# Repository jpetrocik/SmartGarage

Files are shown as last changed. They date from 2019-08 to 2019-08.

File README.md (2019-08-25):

# SmartGarage

SmartGarage is a WIFI enabled device that works with most garage door openers. Along with opening and closing the garage door, it provides the current status of the door, whether its open or closed.  The stock firmware provides both a HTTP Restful api and MQTT based interface. No 3rd party servers are required for SmartGarage to work, you can directly operate it via a HTTP RestAPI or MQTT.  It easly intergrates with HomeAssistant, https://www.home-assistant.io/ and other home automation software.

## Controlling The Garage Door ##

RESTful Api

```
GET  http://garage.local/
Returns the current status of the door, e.g. open or closed

GET  http://garage.local/door
Operates the door, either closing it or opening it depending on what the current status is.

GET http://garage.local/config
Returns the current configuration

PUT http://garage.local/config?poperty_name=property_value
Sets the configuration property to the provided value

GET http://garage.local/restart
Reboot the device

POST http://garage.local/factoryreset
Resets the device to factory settings
```

MQTT

MQTT is a common messaging protocol used for IoT devices.  Most home automation systems like OpenHab and home-assistant.io  support mqtt messaging. If you are unfamiliar with MQTT, check out https://mosquitto.org/ to learn more.

The device listens on the command topic and publishes the status of the door on the status topic.  The command topic is used to send commands to the device to operate the garage door. The default hostname for the device is __garage__, below replace [hostname] with the hostname of the device.  If you have not changed it, it will be __garage__. 

```
garage/[hostname]/command
```

The messages published to the command topic are very simple,  just numeric numbers.  You can request the door to close, open, or toggle depending on its current state.
```
0 Close the door 
1 Open the door 
2 Toggle the door, open or close depending on current state
3 Request current status
```

If you are using mosquito the command line to open the garage door would look like this:

```
mosquito_pub -t garage/garage/command -m 1
```

When the door opens or closes, the status is published on the status topic.  The message is a json message indicating the current status.  Again, if using mosquito the command line to listen for the status change would be

```
mosquito_sub -t garage/garage/status 
```

Here is an example of the message published with the door is closed.

```
{
  "status": "CLOSED"
}
```

## Installation Guide ##

https://docs.google.com/document/d/12LUHNYjrVlYSZdDVwD1QsqcnY-EzrYETPhFzhXXMPhE/edit?usp=sharing

## Device ##

The physical PCB is about 20mm x 40mm and is powered by a mini usb cable.  Installation is straight forward and does not interfere the current operation of the garage door, all remotes and openers still work.

There are a couple options to get your hands on your own board.  You can order it directly from me on ebay.com with the latest firmware already flashed and ready to install, or you can download the Eagle files from https://github.com/jpetrocik/SmartGarage and build your own.

Image Of Device v1.1

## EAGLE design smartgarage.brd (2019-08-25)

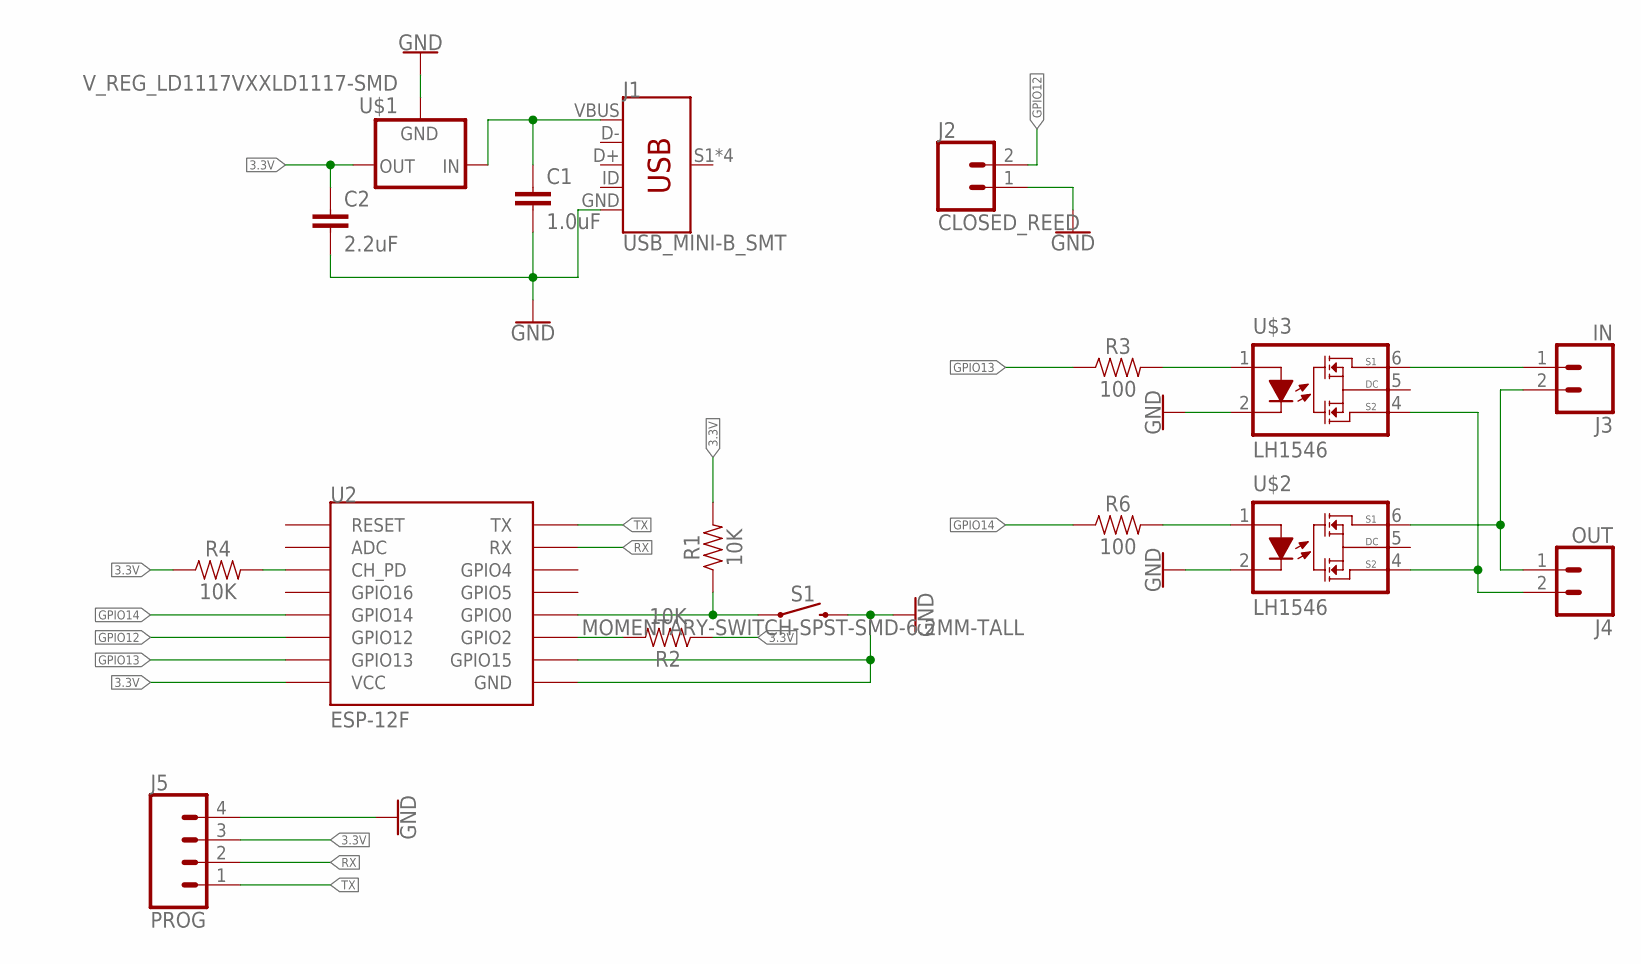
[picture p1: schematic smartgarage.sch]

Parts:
C1: 1.0uF; 0805
C2: 2.2uF; 0805
J1: USB_MINI-B_SMT; USB-MINIB
J2: CLOSED_REED; SCREWTERMINAL-3.5MM-2-NS
J3: IN; SCREWTERMINAL-3.5MM-2-NS
J4: OUT; SCREWTERMINAL-3.5MM-2-NS
J5: PROG; 1X04
R1, R2, R4: 10K; 0805
R3, R6: 100; 0805
S1: MOMENTARY-SWITCH-SPST-SMD-6.2MM-TALL; TACTILE_SWITCH_SMD_6.2MM_TALL
U2: ESP-12F; ESP12-SMD
U$1: V_REG_LD1117VXXLD1117-SMD; SOT223
U$2, U$3: LH1546; DIL6-SMD

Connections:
3.3V: C2.1, J5.3, R1.2, R2.1, R4.1, U2.VCC, U$1.2 (OUT)
GND: C1.2, C2.2, J1.GND, J2.1, J5.4, S1.B2 (2), U2.GND, U2.GPIO15, U$1.1 (GND), U$2.2 (C), U$3.2 (C)
GPIO12: J2.2, U2.GPIO12
GPIO13: R3.1, U2.GPIO13
GPIO14: R6.1, U2.GPIO14
unnamed: R1.1, S1.A2 (1), U2.GPIO0
unnamed: R6.2, U$2.1 (A)
unnamed: R4.2, U2.CH_PD
unnamed: R2.2, U2.GPIO2
unnamed: J3.2, J4.1, U$2.6 (S1)
unnamed: R3.2, U$3.1 (A)
unnamed: J3.1, U$3.6 (S1)
unnamed: J4.2, U$2.4 (S2), U$3.4 (S2)
RX: J5.2, U2.RXD0 (RX)
TX: J5.1, U2.TXD0 (TX)
VBUS: C1.1, J1.VBUS, U$1.3 (IN)

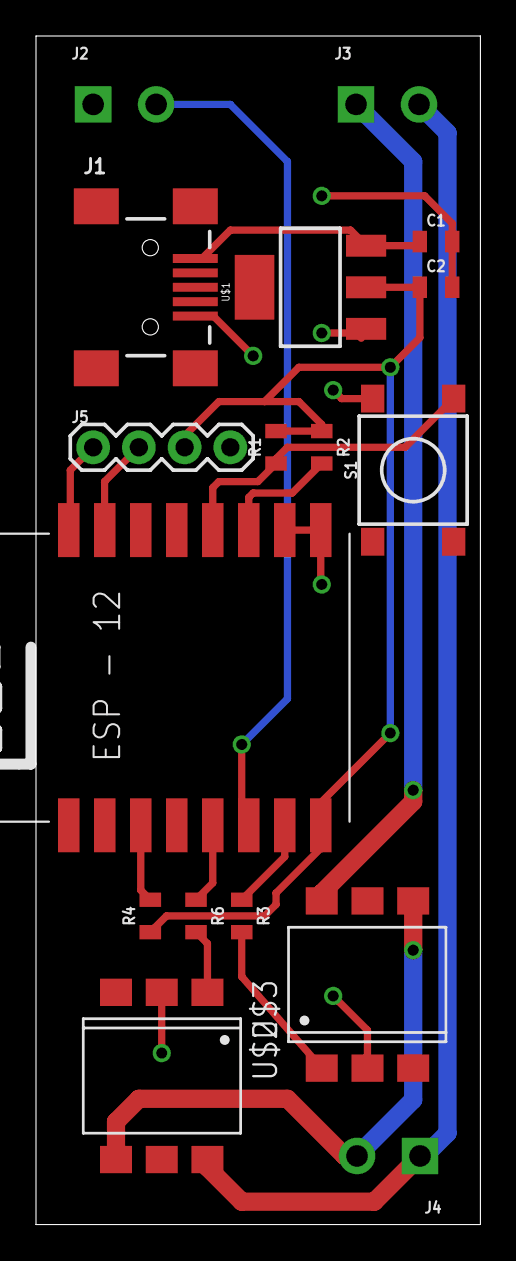
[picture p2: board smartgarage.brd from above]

Board: 2 copper layers, 24.7 x 66.0 mm, 17 parts (0 on the bottom side), 16 nets.

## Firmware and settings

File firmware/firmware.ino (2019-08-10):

#include <FS.h>

#include <ESP8266WiFi.h>          //https://github.com/esp8266/Arduino

//needed for library
#include <ArduinoOTA.h>
#include <DNSServer.h>
#include <WiFiManager.h>         //https://github.com/tzapu/WiFiManager
#include <Ticker.h>
#include <ArduinoJson.h>
#include <ESP8266mDNS.h>
#include <PubSubClient.h>

#include <WiFiClient.h>
#include <ESP8266WebServer.h>
#include <Bounce2.h>

#include "configuration.h"

Ticker ticker;

Bounce doorSwitch = Bounce();

char jsonStatusMsg[140];

//configuration properties
char mqttServer[150] = MQTT_SERVER;
int mqttServerPort = MQTT_PORT;
boolean mqttSsl = false;
char mqttUsername[150];
char mqttPassword[150];

char hostname[20];
char commandTopic[150];
char statusTopic[150];

void setup() {
  Serial.begin(115200);

  pinMode(ONBOARD_LED, OUTPUT);
  pinMode(RELAY, OUTPUT);

  //setup pin read with bounce protection and door bouncing when it opens
  doorSwitch.attach(DOOR_STATUS, INPUT_PULLUP); 
  doorSwitch.interval(500);

  sprintf (hostname, "garage");
  
  //slow ticker when starting up
  //switch to fast tick when in AP mode
  ticker.attach(0.6, tick);

  configLoad();

  wifiSetup();

  mdnsSetup();

#ifdef OTA_ENABLED
  otaSetup();
#endif  

  mqttSetup();

  webServerSetup();

  ticker.detach();

  Serial.println("SmartGarage Firmware");
  Serial.println(__DATE__ " " __TIME__);

}

void loop() {

  mqttLoop();

#ifdef OTA_ENABLED
  otaLoop();
#endif  

  webServerLoop();

  sendDoorStatusOnChange();
}

void openDoor() {
  if (!doorSwitch.read()) {
    toogleDoor();
  }
}

void closeDoor() {
  if (doorSwitch.read()) {
    toogleDoor();
  }
}

void toogleDoor() {
  ticker.attach(0.2, tick);
  digitalWrite(RELAY, HIGH);
  delay(500);
  digitalWrite(RELAY, LOW);
}

void sendCurrentDoorStatus(boolean changed) {
  int doorState = !doorSwitch.read();
  sprintf (jsonStatusMsg, "{\"status\":%s, \"changed\":%s}", doorState ? "\"CLOSED\"" : "\"OPEN\"", changed ? "true" : "false");

  mqttSendMsg(jsonStatusMsg);
}

void sendDoorStatusOnChange() {
  boolean changed = doorSwitch.update();

  //if the button state has changed, current state is recorded
  if (changed) {
    ticker.detach();
    sendCurrentDoorStatus(changed);
    int doorState = !doorSwitch.read();
    digitalWrite(ONBOARD_LED, doorState);
  }

}

void factoryReset() {
  Serial.println("Restoring Factory Setting....");
  WiFi.disconnect();
  SPIFFS.format();
  ESP.eraseConfig();
  Serial.println("Restarting....");
  delay(500);
  ESP.restart();
}

void tick() {
  int state = digitalRead(ONBOARD_LED);
  digitalWrite(ONBOARD_LED, !state);
}

//Called to save the configuration data after
//the device goes into AP mode for configuration
void configSave() {
  DynamicJsonDocument jsonDoc(1024);
  JsonObject json = jsonDoc.to<JsonObject>();

  //standard properties, allways shown when view config
  json["hostname"] = hostname;
  json["mqttServer"] = mqttServer;
  json["mqttServerPort"] = mqttServerPort;
  json["mqttSsl"] = mqttSsl;
  json["mqttUsername"] = mqttUsername;
  json["mqttPassword"] = mqttPassword;

  //advanced properties, only show in config if set
  if (strlen(commandTopic))
    json["commandTopic"] = commandTopic;
  if (strlen(statusTopic))
    json["statusTopic"] = statusTopic;

  File configFile = SPIFFS.open("/config.json", "w");
  if (configFile) {
    Serial.println("Saving config data....");
    serializeJson(json, Serial);
    Serial.println();
    serializeJson(json, configFile);
    configFile.close();
  }
}

//Loads the configuration data on start up
void configLoad() {
  Serial.println("Loading config data....");
  if (SPIFFS.begin()) {
    if (SPIFFS.exists("/config.json")) {
      //file exists, reading and loading
      File configFile = SPIFFS.open("/config.json", "r");
      if (configFile) {
        size_t size = configFile.size();
        std::unique_ptr<char[]> buf(new char[size]);

        configFile.readBytes(buf.get(), size);

        DynamicJsonDocument jsonDoc(size);
        DeserializationError error = deserializeJson(jsonDoc, buf.get());
        serializeJsonPretty(jsonDoc, Serial);

        JsonObject json = jsonDoc.as<JsonObject>();
        if (json.containsKey("hostname")) {
          strncpy(hostname, json["hostname"], 20);
        }

        if (json.containsKey("mqttServer")) {
          strncpy(mqttServer, json["mqttServer"], 150);
        }

        if (json.containsKey("mqttUsername")) {
          strncpy(mqttUsername, json["mqttUsername"], 150);
        }

        if (json.containsKey("mqttPassword")) {
          strncpy(mqttPassword, json["mqttPassword"], 150);
        }

        if (json.containsKey("mqttServerPort")) {
          mqttServerPort = json["mqttServerPort"];
        }

        if (json.containsKey("mqttSsl")) {
          mqttSsl = json["mqttSsl"];
        }

        if (json.containsKey("commandTopic")) {
          strncpy(commandTopic, json["commandTopic"], 150);
        }

        if (json.containsKey("statusTopic")) {
          strncpy(statusTopic, json["statusTopic"], 150);
        }

      }
    }
  }
}

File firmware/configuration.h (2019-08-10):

#ifndef Configuration_h
#define Configuration_h

//Board version, found on the back of the board
#define VERSION_1_1 1
#define VERSION_1_2 2

//Define the board version
#define BOARD_VERSION VERSION_1_2

//To enable OTA updates
#define OTA_ENABLED

//Defaults to mDns look up of mqtt, change to server name or ip
#define MQTT_SERVER "mqtt.local"
#define MQTT_PORT 1883

//v1.1 PINOUTS
#if BOARD_VERSION == VERSION_1_1
  #define ONBOARD_LED 2
  #define DOOR_STATUS 12
  #define RELAY 14
#endif

//v1.2 PINOUTS
#if BOARD_VERSION == VERSION_1_2
  #define ONBOARD_LED 2
  #define DOOR_STATUS 12
  #define RELAY 14
  #define DOOR_LOCK 13
#endif




#endif

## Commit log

2019-03-12 V1.2 - Rotated ESP, add lock
    [smartgarage.brd, smartgarage.sch]
2019-03-14 Adding firmward to project
    [configuration.h, smartgarage.brd]
2019-03-15 Cleaned up device description
2019-03-15 Add support for both secure and unsecure mqtt
    [configuration.h]
2019-03-15 Added image of device
2019-08-10 Updated for v1.2
    [configuration.h]
2019-08-25 Hardware 1.2.1, moved screw terminal
    [smartgarage.brd]

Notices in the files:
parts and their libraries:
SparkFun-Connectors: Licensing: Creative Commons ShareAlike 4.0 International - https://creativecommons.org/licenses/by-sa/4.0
